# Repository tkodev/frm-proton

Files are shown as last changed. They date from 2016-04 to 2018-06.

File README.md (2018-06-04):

---
layout: _pages/post
title: Proton Light Switch
date: '2016-06-01'
link: 'https://www.youtube.com/watch?v=7FFnYyeRKBw'
code: 'https://github.com/htkoca/iot-proton-switch'
categories:
  - code
tags:
  - C++
  - IoT
  - photon
  - arduino
  - infrared
cover: cover.jpg
images:
  - wallplate.jpg
  - fixture.jpg
  - fixture-back.jpg
---
# Personal Project
This is a custom built wifi enabled smart switch I’ve built for personal use. It also is connected to my garage door opener, and has a built in IR blaster. DHT 22 temperature sensor is also present to check for overheating.

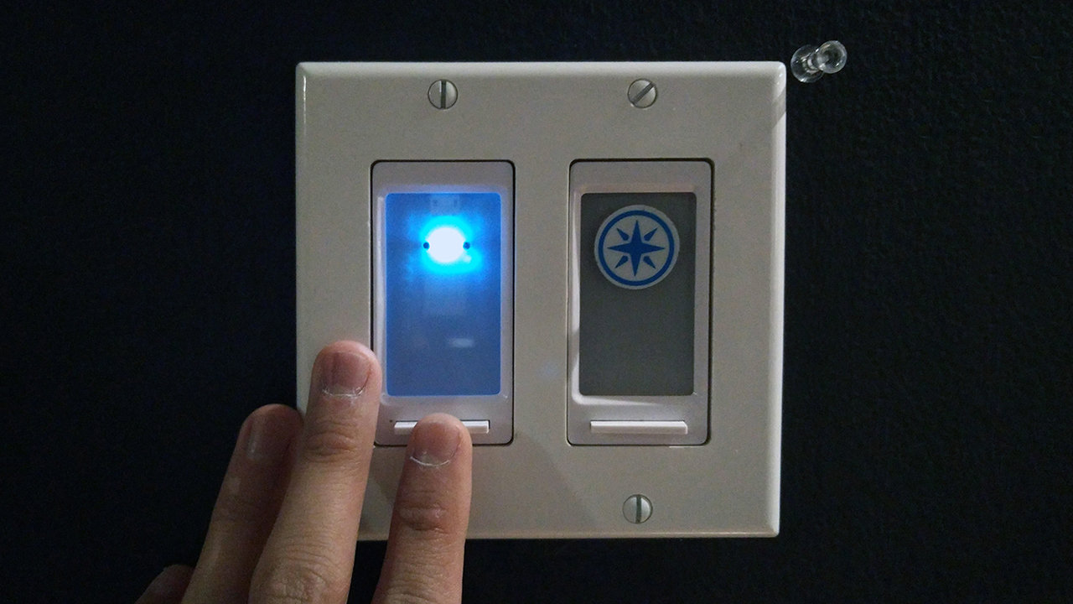
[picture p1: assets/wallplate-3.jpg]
App Screenshot


## Project Criteria:
* Microcontroller: Particle.io (Particle Photon)
* Garage Door Remote: Craftsman 315mhz Remote
* Light Switch: 2CH 3.3-5V Relay Kit
* Temp Sensor: DHT 22
* IR Emitter: TSAL6100
* IR Recorder: TSOP34438
* Pseudo MVC approach: Event Assignment > Events > Action

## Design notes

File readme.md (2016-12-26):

---
type: "folio"
draft: false
date: "2016-06-01"
title: "Proton Smart Light Switch"
parent: "personal"
topics:
  - "code"
tools:
  - "personal"
  - "C++"
  - "IoT"
  - "particle"
  - "photon"
  - "arduino"
  - "smart"
  - "infrared"
cover: "cover.png"
photo:
  - "wallplate.png"
  - "fixture.png"
  - "fixture-back.png"
link: "https://github.com/htko89/proton"
version: "0.2.0"
---
# Personal Project
This is a custom built wifi enabled smart switch I’ve built for personal use. It also is connected to my garage door opener, and has a built in IR blaster. DHT 22 temperature sensor is also present to check for overheating.

## Project Criteria:
Microcontroller: Particle.io (Particle Photon)
Garage Door Remote: Craftsman 315mhz Remote
Light Switch: 2CH 3.3-5V Relay Kit
Temp Sensor: DHT 22
IR Emitter: TSAL6100
IR Recorder: TSOP34438
Pseudo MVC approach: Event Assignment > Events > Action

## Project Views:
Working Model (various views)

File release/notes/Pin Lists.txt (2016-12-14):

To do:
	
D7 - Reed Sensor D0-6 x1 0
	use internal pull-up resistor 
	requires ground

D6 - DHT - D3 x1 (working on D2,4) #done -
	0.) 1 2 - 4
	1.) positive
	2.) pin + (4.7k) pullup resistor
	4.) negative
	requires ground and 3v
		use FLOAT or DOUBLE to store results
		5v tolerant - must test

A4 - IR LED Control D0-3 x1 #done 
	IR LED
		FV (V): 1.5~1.6
		FC (mA): 60mA, 120mA peak for 10% Pulse Width
		35ma at 100r
		75ma at 47r
		I used 22r
	2N2222
		flat side up:
		3E-tognd 2B-topin 1C-positive in
			To control a 5v LED at 100ma, use a 2kr base resistor
				Value calculated with transistor calculator
			what did I use?
		requires ground to 5v
A5 - Capture (with a transistor), A0-5/D0-6 x1 -
	IR Receiver
		FV (V): 1.1~1.4
		FC (mA): 30 ma; 75 ma peak;
	VS1838B (CMOS lvl digital signal - output matching TTL)
		1-out 2-gnd 3-vcc
		Vcc: 3-5
		Hz: 38Hz
		requires a digital input pin

A2,3 Relay control - D0-6 x2 #Done 65
	requires ground and 5v

A0,1 - Two buttons w/ LEDs - D0-6 x2 #Done -
	LED must run parallel to (200) pulldown resistor
	requires ground and 5v

Notes
	20ma max a pin
	gnd are connected
	All pins except A3 and DAC are 5V tolerant (when not in analog mode). If used as a 5V input the pull-up/pull-down resistor must be disabled.

	Analog pins can be used as Digital Pins too

	D0-3 #2,3 = Analog output via PWM
	A4-5 #4,5 = PWM Analog output

optional - reed switch and remote for garage

when led 

a5 unable to attach interrupt

future:
	research mosfets / dimmer / optocouplers
	experiment with pcb ordering
	experiment wtih low level switching on led

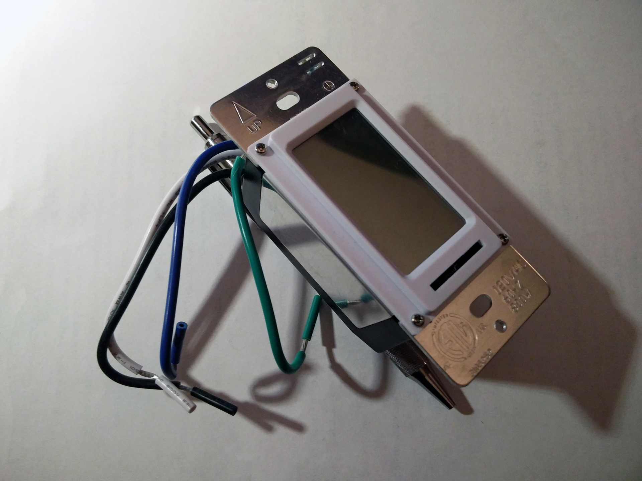
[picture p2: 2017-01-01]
assets/fixture.jpg

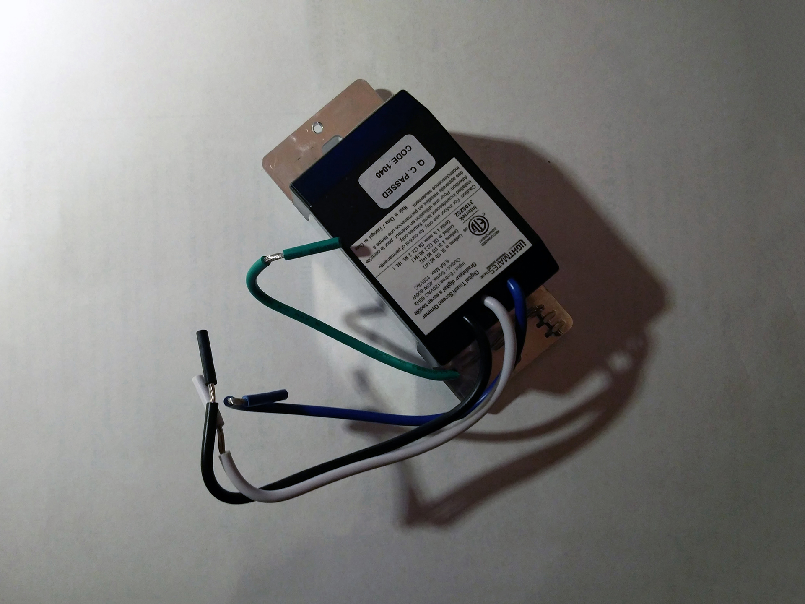
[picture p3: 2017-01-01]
assets/fixture-back.jpg

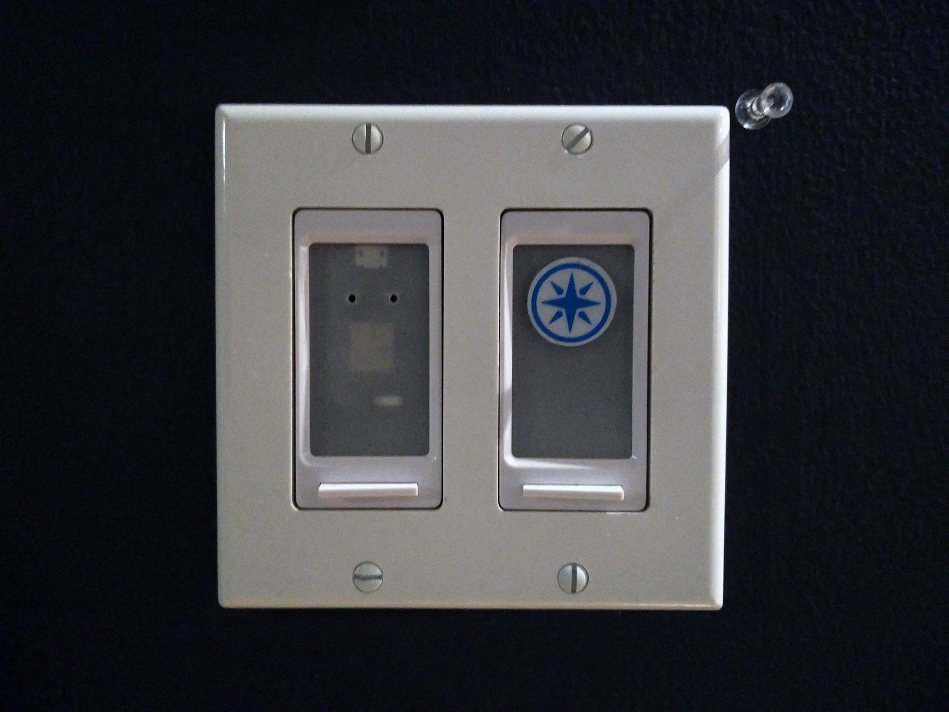
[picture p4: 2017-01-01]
assets/wallplate.jpg

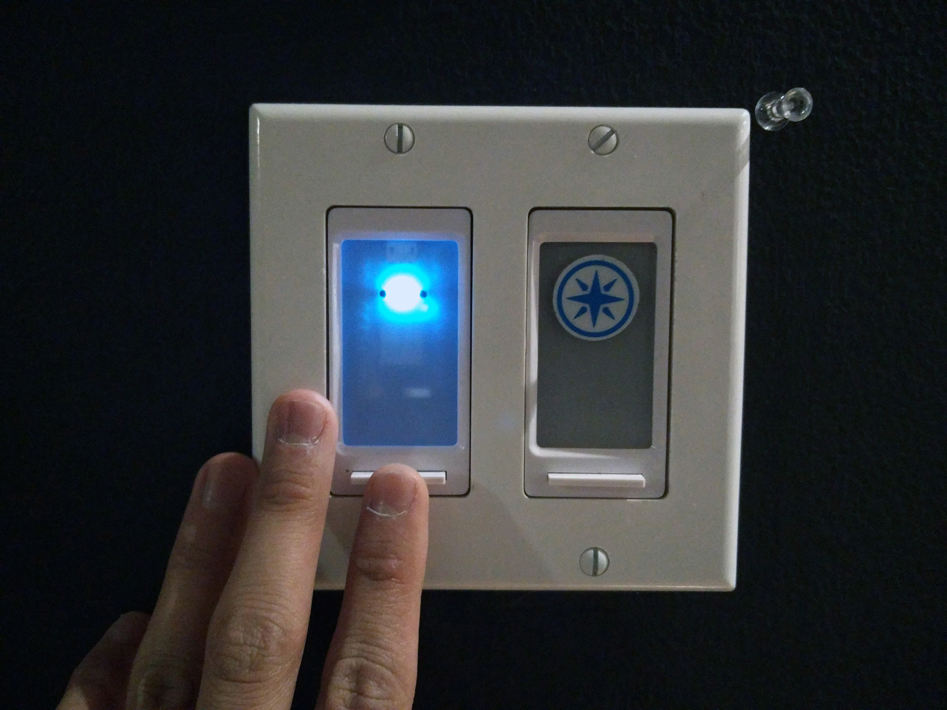
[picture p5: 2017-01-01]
assets/wallplate-1.jpg

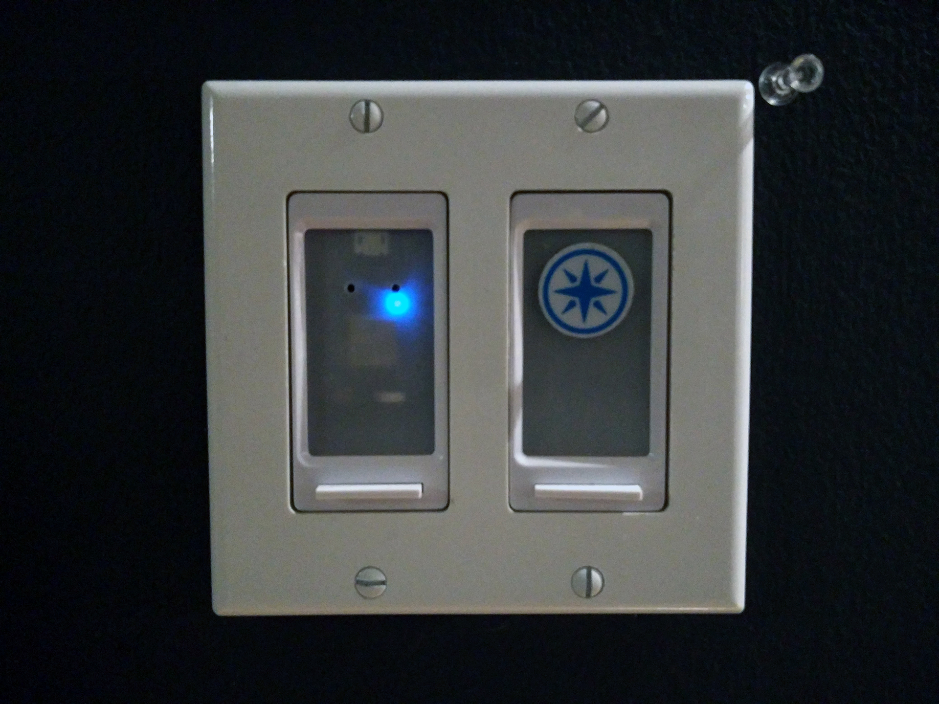
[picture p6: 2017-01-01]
assets/wallplate-2.jpg

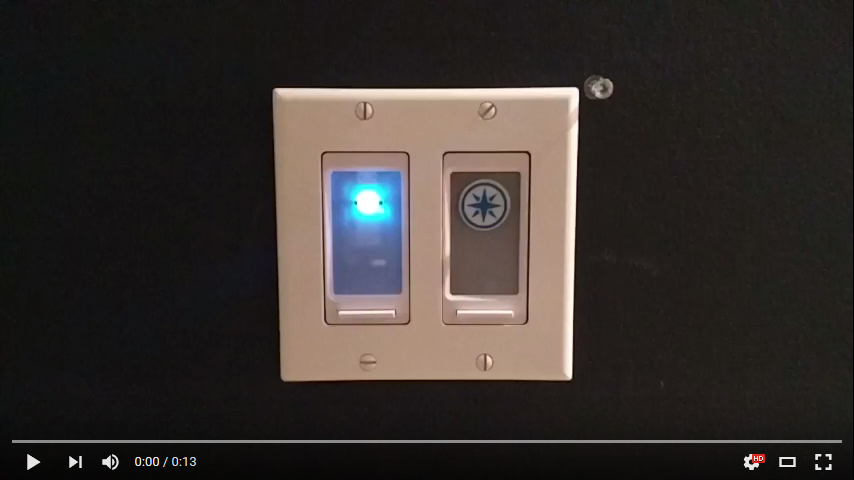
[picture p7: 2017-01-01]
assets/youtube.jpg

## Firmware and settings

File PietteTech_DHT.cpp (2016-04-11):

/*
 * FILE:        PietteTech_DHT.cpp
 * VERSION:     0.3
 * PURPOSE:     Spark Interrupt driven lib for DHT sensors
 * LICENSE:     GPL v3 (http://www.gnu.org/licenses/gpl.html)
 *
 * S Piette (Piette Technologies) scott.piette@gmail.com
 *      January 2014        Original Spark Port
 *      October 2014        Added support for DHT21/22 sensors
 *                          Improved timing, moved FP math out of ISR
 *
 * Based on adaptation by niesteszeck (github/niesteszeck)
 * Based on original DHT11 library (http://playgroudn.adruino.cc/Main/DHT11Lib)
 *
 * This library supports the DHT sensor on the following pins
 * D0, D1, D2, D3, D4, A0, A1, A3, A5, A6, A7
 * http://docs.spark.io/firmware/#interrupts-attachinterrupt
 */
/*
    Timing of DHT22 SDA signal line after MCU pulls low for 1ms
    https://github.com/mtnscott/Spark_DHT/AM2302.pdf

  - - - -            -----           -- - - --            ------- - -
         \          /     \         /  \      \          /
          +        /       +       /    +      +        /
           \      /         \     /      \      \      /
            ------           -----        -- - --------
 ^        ^                ^                   ^          ^
 |   Ts   |        Tr      |        Td         |    Te    |

    Ts : Start time from MCU changing SDA from Output High to Tri-State (Hi-Z)
         Spec: 20-200us             Tested: < 65us
    Tr : DHT response to MCU controlling SDA and pulling Low and High to
         start of first data bit
         Spec: 150-170us            Tested: 125 - 200us
    Td : DHT data bit, falling edge to falling edge
         Spec: '0' 70us - 85us      Tested: 60 - 110us
         Spec: '1' 116us - 130us    Tested: 111 - 155us
    Te : DHT releases SDA to Tri-State (Hi-Z)
         Spec: 45-55us              Not Tested
 */

#include "application.h"
#include "math.h"
#include "PietteTech_DHT.h"

// Thanks to Paul Kourany for this word type conversion function
uint16_t word(uint8_t high, uint8_t low) {
    uint16_t ret_val = low;
    ret_val += (high << 8);
    return ret_val;
}

PietteTech_DHT::PietteTech_DHT(uint8_t sigPin, uint8_t dht_type, void (*callback_wrapper)()) {
    begin(sigPin, dht_type, callback_wrapper);
    _firstreading = true;
}

void PietteTech_DHT::begin(uint8_t sigPin, uint8_t dht_type, void (*callback_wrapper) ()) {
    _sigPin = sigPin;
    _type = dht_type;
    isrCallback_wrapper = callback_wrapper;

    pinMode(sigPin, OUTPUT);
    digitalWrite(sigPin, HIGH);
    _lastreadtime = 0;
    _state = STOPPED;
    _status = DHTLIB_ERROR_NOTSTARTED;
}

int PietteTech_DHT::acquire() {
    // Check if sensor was read less than two seconds ago and return early
    // to use last reading
    unsigned long currenttime = millis();
    if (currenttime < _lastreadtime) {
        // there was a rollover
        _lastreadtime = 0;
    }
    if (!_firstreading && ((currenttime - _lastreadtime) < 2000 )) {
        // return last correct measurement, (this read time - last read time) < device limit
        return DHTLIB_ACQUIRED;
    }

    if (_state == STOPPED || _state == ACQUIRED) {
        /*
         * Setup the initial state machine
         */
        _firstreading = false;
        _lastreadtime = currenttime;
        _state = RESPONSE;

#if defined(DHT_DEBUG_TIMING)
        /*
         * Clear the debug timings array
         */
        for (int i = 0; i < 41; i++) _edges[i] = 0;
        _e = &_edges[0];
#endif

        /*
         * Set the initial values in the buffer and variables
         */
        for (int i = 0; i < 5; i++) _bits[i] = 0;
        _cnt = 7;
        _idx = 0;
        _hum = 0;
        _temp = 0;

        /*
         * Toggle the digital output to trigger the DHT device
         * to send us temperature and humidity data
         */
        pinMode(_sigPin, OUTPUT);
        digitalWrite(_sigPin, LOW);
        if (_type == DHT11)
            delay(18);                  // DHT11 Spec: 18ms min
        else
            delayMicroseconds(1500);    // DHT22 Spec: 0.8-20ms, 1ms typ
        pinMode(_sigPin, INPUT);        // Note Hi-Z mode with pullup resistor
                                        // will keep this high until the DHT responds.
        /*
         * Attach the interrupt handler to receive the data once the DHT
         * starts to send us data
         */
        _us = micros();
        attachInterrupt(_sigPin, isrCallback_wrapper, FALLING);

        return DHTLIB_ACQUIRING;
    } else
        return DHTLIB_ERROR_ACQUIRING;
}

int PietteTech_DHT::acquireAndWait(uint32_t timeout=0) {
    acquire();
    uint32_t start = millis();
    uint32_t wrapper;
    while(acquiring() && (timeout == 0 || (millis() > start && (millis()-start) < timeout)));
    if (timeout)
    {
        if (millis() < start) // millis counter wrapped
        {
            wrapper = (~start)+1;   // Compute elapsed seconds between "start" and counter-wrap to 0
            timeout -= wrapper;     // Subtract elapsed seconds to 0 from timeout
        }
        // If millis counter didn't wrap, the next line will be a no-op.
        while(acquiring() && (millis() < timeout));
    }
    return getStatus();
}
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

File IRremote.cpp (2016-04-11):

/*
 * IRremote
 * Version 0.11 August, 2009
 * Copyright 2009 Ken Shirriff
 * For details, see http://arcfn.com/2009/08/multi-protocol-infrared-remote-library.html
 * Modified by Paul Stoffregen <paul@pjrc.com> to support other boards and timers
 * Modified  by Mitra Ardron <mitra@mitra.biz>
 * Added Sanyo and Mitsubishi controllers
 * Modified Sony to spot the repeat codes that some Sony's send
 * Modified by Gaspard van Koningsveld to trim out IRrecv, not using PWM anymore, allow setting of IR LED pin, and make it compatible with the Spark Core v1.0 (STM32F103CB based)
 * Interrupt code based on NECIRrcv by Joe Knapp
 * http://www.arduino.cc/cgi-bin/yabb2/YaBB.pl?num=1210243556
 * Also influenced by http://zovirl.com/2008/11/12/building-a-universal-remote-with-an-arduino/
 * JVC and Panasonic protocol added by Kristian Lauszus (Thanks to zenwheel and other people at the original blog post)
 */

#include "IRremote.h"
#include "application.h"

IRsend::IRsend(int irPins) : irPin(irPin) {
  //
};

void IRsend::sendNEC(unsigned long data, int nbits){
  enableIROut(38);
  mark(NEC_HDR_MARK);
  space(NEC_HDR_SPACE);
  for (int i = 0; i < nbits; i++) {
    if (data & TOPBIT) {
      mark(NEC_BIT_MARK);
      space(NEC_ONE_SPACE);
    }
    else {
      mark(NEC_BIT_MARK);
      space(NEC_ZERO_SPACE);
    }
    data <<= 1;
  }
  mark(NEC_BIT_MARK);
  space(0);
}

void IRsend::sendSony(unsigned long data, int nbits){
  enableIROut(40);
  mark(SONY_HDR_MARK);
  space(SONY_HDR_SPACE);
  data = data << (32 - nbits);
  for (int i = 0; i < nbits; i++) {
    if (data & TOPBIT) {
      mark(SONY_ONE_MARK);
      space(SONY_HDR_SPACE);
    }
    else {
      mark(SONY_ZERO_MARK);
      space(SONY_HDR_SPACE);
    }
    data <<= 1;
  }
}

void IRsend::sendRaw(unsigned int buf[], int len, int hz){
  enableIROut(hz);
  for (int i = 0; i < len; i++) {
    if (i & 1) {
      space(buf[i]);
    }
    else {
      mark(buf[i]);
    }
  }
  space(0); // Just to be sure
}

void IRsend::sendRC5(unsigned long data, int nbits){ // Note: first bit must be a one (start bit)
  enableIROut(36);
  data = data << (32 - nbits);
  mark(RC5_T1); // First start bit
  space(RC5_T1); // Second start bit
  mark(RC5_T1); // Second start bit
  for (int i = 0; i < nbits; i++) {
    if (data & TOPBIT) {
      space(RC5_T1); // 1 is space, then mark
      mark(RC5_T1);
    }
    else {
      mark(RC5_T1);
      space(RC5_T1);
    }
    data <<= 1;
  }
  space(0); // Turn off at end
}

void IRsend::sendRC6(unsigned long data, int nbits){ // Caller needs to take care of flipping the toggle bit
  enableIROut(36);
  data = data << (32 - nbits);
  mark(RC6_HDR_MARK);
  space(RC6_HDR_SPACE);
  mark(RC6_T1); // start bit
  space(RC6_T1);
  int t;
  for (int i = 0; i < nbits; i++) {
    if (i == 3) {
      // double-wide trailer bit
      t = 2 * RC6_T1;
    }
    else {
      t = RC6_T1;
    }
    if (data & TOPBIT) {
      mark(t);
      space(t);
    }
    else {
      space(t);
      mark(t);
    }

    data <<= 1;
  }
  space(0); // Turn off at end
}

/* Sharp and DISH support by Todd Treece ( http://unionbridge.org/design/ircommand )
 * The Dish send function needs to be repeated 4 times, and the Sharp function has the necessary repeat built in because of the need to invert the signal.
 *
 * Sharp protocol documentation:
 * http://www.sbprojects.com/knowledge/ir/sharp.htm
 * Here are the LIRC files that I found that seem to match the remote codes
 * from the oscilloscope:
 * Sharp LCD TV:
 * http://lirc.sourceforge.net/remotes/sharp/GA538WJSA
 * DISH NETWORK (echostar 301):
 * http://lirc.sourceforge.net/remotes/echostar/301_501_3100_5100_58xx_59xx
 *
 * For the DISH codes, only send the last for characters of the hex.
 * i.e. use 0x1C10 instead of 0x0000000000001C10 which is listed in the
 * linked LIRC file.
 */
void IRsend::sendSharp(unsigned long data, int nbits){
  unsigned long invertdata = data ^ SHARP_TOGGLE_MASK;
  enableIROut(38);
  for (int i = 0; i < nbits; i++) {
    if (data & 0x4000) {
      mark(SHARP_BIT_MARK);
      space(SHARP_ONE_SPACE);
    }
    else {
      mark(SHARP_BIT_MARK);
      space(SHARP_ZERO_SPACE);
    }
    data <<= 1;
  }

  mark(SHARP_BIT_MARK);
  space(SHARP_ZERO_SPACE);
  delay(46);
  for (int i = 0; i < nbits; i++) {
    if (invertdata & 0x4000) {
      mark(SHARP_BIT_MARK);
      space(SHARP_ONE_SPACE);
    }
    else {
      mark(SHARP_BIT_MARK);
      space(SHARP_ZERO_SPACE);
    }
    invertdata <<= 1;
  }
  mark(SHARP_BIT_MARK);
  space(SHARP_ZERO_SPACE);
  delay(46);
}

void IRsend::sendDISH(unsigned long data, int nbits){
  enableIROut(56);
  mark(DISH_HDR_MARK);
  space(DISH_HDR_SPACE);
  for (int i = 0; i < nbits; i++) {
    if (data & DISH_TOP_BIT) {
      mark(DISH_BIT_MARK);
      space(DISH_ONE_SPACE);
    }
    else {
      mark(DISH_BIT_MARK);
      space(DISH_ZERO_SPACE);
    }
    data <<= 1;
  }
}

void IRsend::sendPanasonic(unsigned int address, unsigned long data){
    enableIROut(35);
    mark(PANASONIC_HDR_MARK);
    space(PANASONIC_HDR_SPACE);

    for(int i=0;i<16;i++)
    {
        mark(PANASONIC_BIT_MARK);
        if (address & 0x8000) {
            space(PANASONIC_ONE_SPACE);
        } else {
            space(PANASONIC_ZERO_SPACE);
        }
        address <<= 1;
    }
    for (int i=0; i < 32; i++) {
        mark(PANASONIC_BIT_MARK);
        if (data & TOPBIT) {
            space(PANASONIC_ONE_SPACE);
        } else {
            space(PANASONIC_ZERO_SPACE);
        }
        data <<= 1;
    }
    mark(PANASONIC_BIT_MARK);
    space(0);
}

void IRsend::sendJVC(unsigned long data, int nbits, int repeat){
    enableIROut(38);
    data = data << (32 - nbits);
    if (!repeat){
        mark(JVC_HDR_MARK);
        space(JVC_HDR_SPACE);
    }
    for (int i = 0; i < nbits; i++) {
        if (data & TOPBIT) {
            mark(JVC_BIT_MARK);
            space(JVC_ONE_SPACE);
        }
        else {
            mark(JVC_BIT_MARK);
            space(JVC_ZERO_SPACE);
        }
        data <<= 1;
    }
    mark(JVC_BIT_MARK);
    space(0);
}

void IRsend::mark(int time){
  // Sends an IR mark (frequency burst output) for the specified number of microseconds.
  noInterrupts();
  while (time > 0) {
    digitalWrite(irPin, HIGH); // this takes about 3 microseconds to happen
    delayMicroseconds(burstWait);
    digitalWrite(irPin, LOW); // this also takes about 3 microseconds
    delayMicroseconds(burstWait);

    time -= burstLength;
  }
  interrupts();
}

void IRsend::space(int time){
  // Sends an IR space (no output) for the specified number of microseconds.
  digitalWrite(irPin, LOW); // Takes about 3 microsecondes
  if (time > 3) {
    delayMicroseconds(time - 3);
  }
}
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

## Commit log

2016-04-11 Moved from ISR (interrupts) to checking in Loop
    This was done because ISR's were highly unreliable and caused system
    crashes.
2016-04-11 updated btnHandler and added first loop check
    added first loop check, presently an issue with btnHandler making the
    garage door opener get random voltages.
2016-04-11 fixed looping issue with btnHandler
    changed setup and timer delays
    added memory checker
    changed init / first daemon
2016-04-11 renamed dht timer to reflect daemon
    note: mem check is in daemon
2016-04-18 Filename change & button feedback removed.
    Filename changed to reflect its type, with ino_Proton.ino being the main
    sketch.
    Button feedback removed to prevent spamming the particle cloud event
    log. (lights turn on and off multiple times a day)
2016-06-16 Removed dht daemon, light timer functions, light expire check.
2016-06-16 (re)added light timer & Door sensor. Door sensor modifies light timer
2016-12-14 Add: Support files. Move: Codebase into folder
    [proton.fzz, proton2.fzz]
2016-12-26 Rename: Folders to match release
    [proton.fzz, proton2.fzz]
2016-12-27 Update: Follow release directory structure
    [proton.fzz, proton2.fzz]
